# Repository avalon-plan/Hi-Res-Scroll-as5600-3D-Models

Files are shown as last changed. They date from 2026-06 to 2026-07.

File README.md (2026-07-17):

High Resolution Scroll Wheel-3D外壳文件
上盖就是原视频博主[Engineer Bo](https://www.youtube.com/@engineerbo)的尺寸，我展示的是打印素体，没有打磨上漆
不想用我的底座，可自己修改
先说说我这个VER3.0版本的问题
1. 径向磁铁用的直径6高2.5mm，我使用了嘉立创的3301PA   白色，磁铁塞入上盖有点不够紧，因此我使用了美纹贴纸贴住了，如果你也是此模型最好修改调小一点，但是一定不要去刻意扩孔（扩孔会导致磁体中心对不准as5600模块上芯片的中心），如果是CNC的话个人觉得没有必要改，也可以不修改此孔

3. 底座限制电池802540的长边加强筋没有考虑到因为电池的保护电路板实际比40mm更长一点，导致我第一次塞入的时候给加强筋直接干断了
4. 底座多的一个顶住开发板的加强筋那一块感觉有点大了，导致焊接电源线的时候，有点卡手，最好把这个加强筋设计的再小一点
5. 底盖是有三个加强筋，一个是卡住侧边开孔的按钮，两个是顶住开发板正面的D2、D3和D10、D9、D8，因此D2、D3、D10、D9、D8不要上锡或者焊接东西。焊接请使用D0 D1 D4 D5 D6 D7 GND 3.3V 5V这几个接口

以上问题我有时间会修改下，打印下一个外壳

固定座使用ver6.0

2. 塞入滚花铜柱M2X4的孔有点大了，搞成了2.95mm。个人感觉最好改成更小的的2.5mm然后使用烙铁塞入，开孔没有考虑到3d打印的尺寸偏差

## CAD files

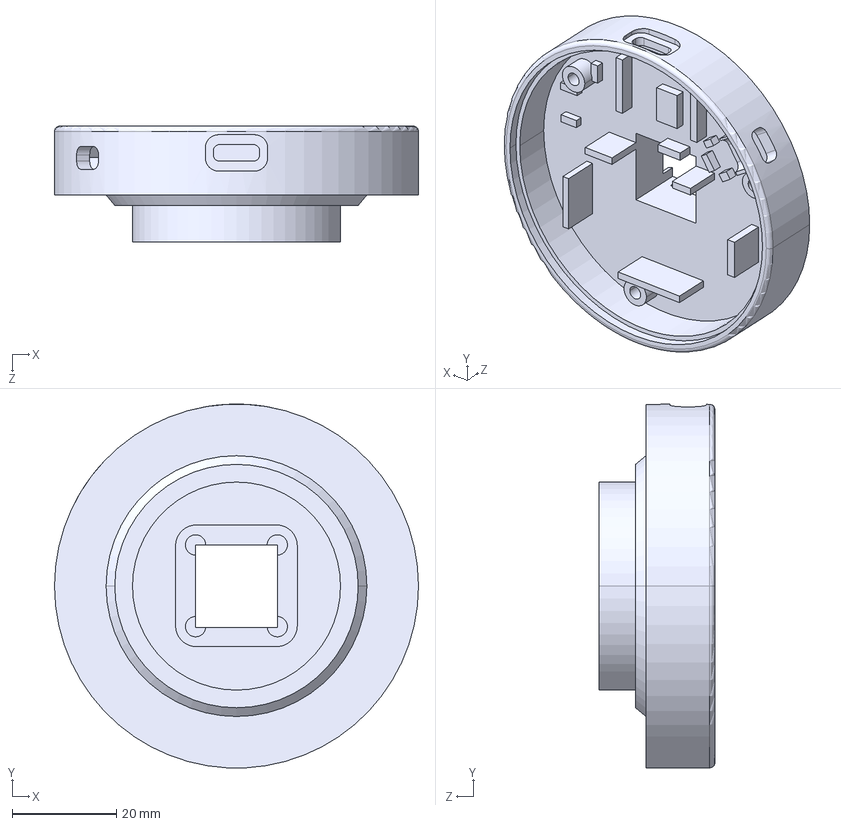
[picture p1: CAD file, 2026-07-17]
VER6.0 固定座.STEP
70.0 x 69.9 x 22.2 mm

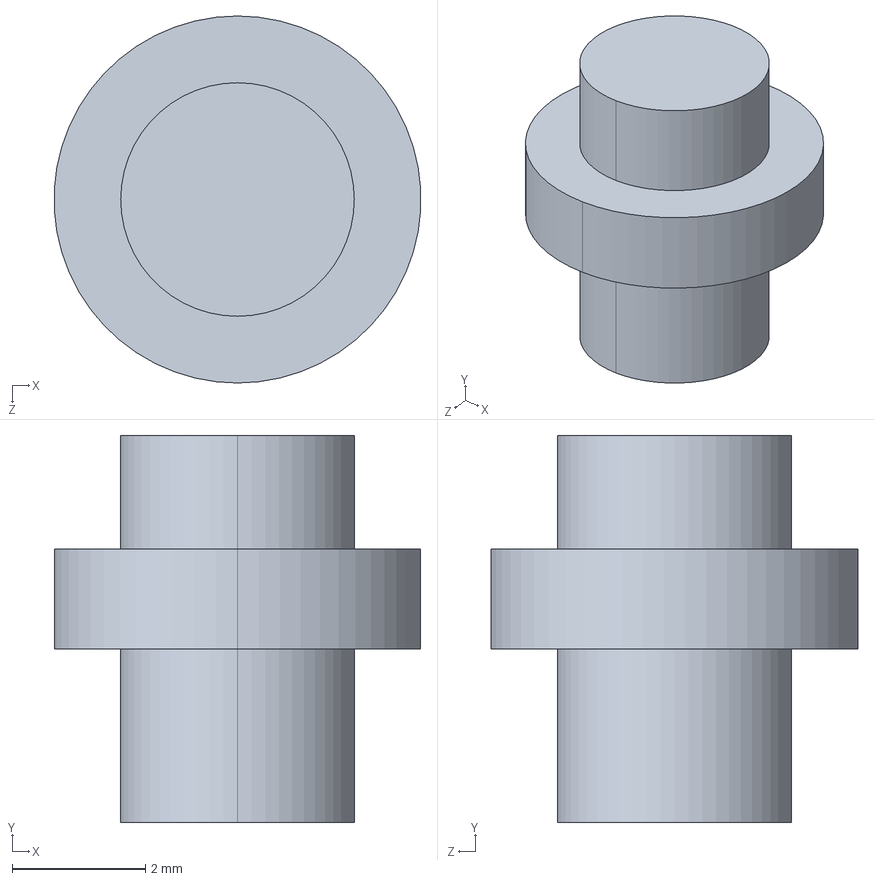
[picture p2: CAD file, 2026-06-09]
VER3.0 按钮2.STEP
5.49 x 5.80 x 5.50 mm

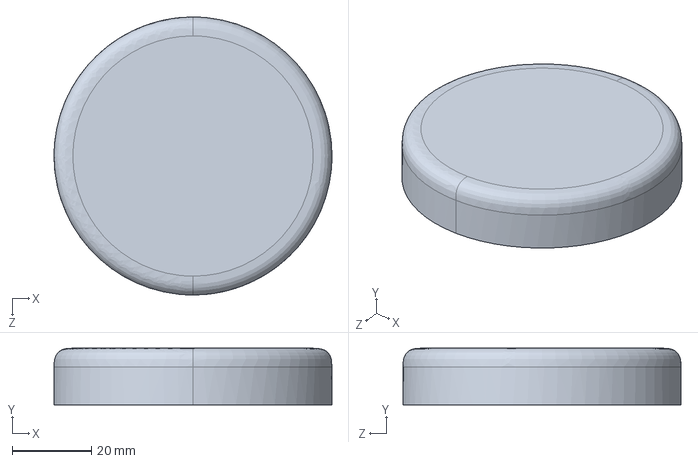
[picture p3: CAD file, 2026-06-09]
VER3.0 上盖.STEP
70.0 x 14.3 x 70.0 mm

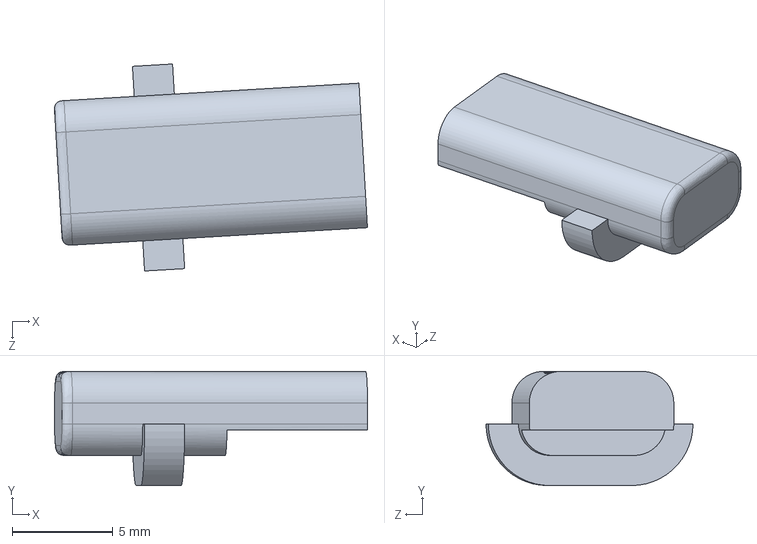
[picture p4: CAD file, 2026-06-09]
VER3.0 切换层按钮.STEP
15.6 x 5.68 x 10.3 mm

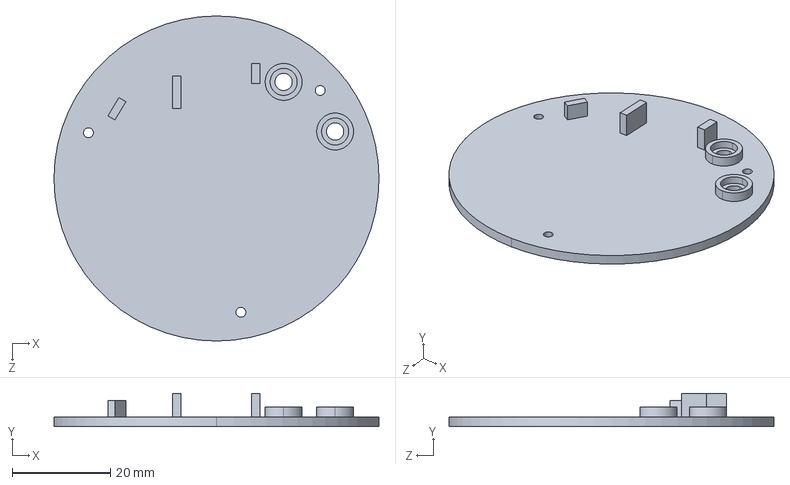
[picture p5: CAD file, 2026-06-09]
VER3.0 底盖.STEP
66.0 x 6.76 x 66.0 mm

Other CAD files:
VER3.0 按钮1.STEP
VER3.0 固定座.STEP
VER3.0 上盖.SLDPRT
VER3.0 切换层按钮.SLDPRT
VER3.0 固定座.SLDPRT
VER3.0 底盖.SLDPRT
VER3.0 按钮1.SLDPRT
VER3.0 按钮2.SLDPRT
VER6.0 固定座.SLDPRT
